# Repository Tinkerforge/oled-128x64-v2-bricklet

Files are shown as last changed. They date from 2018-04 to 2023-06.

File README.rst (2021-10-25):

OLED 128x64 Bricklet 2.0
========================

This repository contains the firmware source code and the hardware design
files. The documentation generator configs can be found at
https://github.com/Tinkerforge/generators

Repository Content
------------------

software/:
 * examples/: Examples for all supported languages
 * build/: Compiled files
 * src/: Source code of firmware
 * Makefile: Makefile to build project

hardware/:
 * Contains KiCad project files and additionally schematics as PDF

datasheets/:
 * Contains datasheets for sensors and complex ICs that are used

Hardware
--------

The hardware is designed with the open source EDA Suite KiCad
(http://www.kicad.org). Before you are able to open the files,
you have to install the Tinkerforge kicad-libraries
(https://github.com/Tinkerforge/kicad-libraries). You can either clone
them directly in hardware/ or clone them in a separate folder and
symlink them into hardware/
(ln -s kicad_path/kicad-libraries project_path/hardware). After that you
can open the .pro file in hardware/ with KiCad and from there view and
modify the schematics and the PCB layout.

Software
--------

If you want to do your own Brick/Bricklet firmware development we highly
recommend that you use our build environment setup script and read the
tutorial (https://www.tinkerforge.com/en/doc/Tutorials/Tutorial_Build_Environment/Tutorial.html).

To compile the C code we recommend you to install the newest GNU Arm Embedded
Toolchain (https://launchpad.net/gcc-arm-embedded/+download).
You also need to install bricklib2 (https://github.com/Tinkerforge/bricklib2).

You can either clone it directly in software/src/ or clone it in a
separate folder and symlink it into software/src/
(ln -s bricklib_path/bricklib2 project_path/software/src/). Finally make sure to
have CMake installed (http://www.cmake.org/cmake/resources/software.html).

After that you can build the firmware by invoking make in software/.
The firmware (.zbin) can then be found in software/build/ and uploaded
with brickv (click button "Flashing" on start screen).

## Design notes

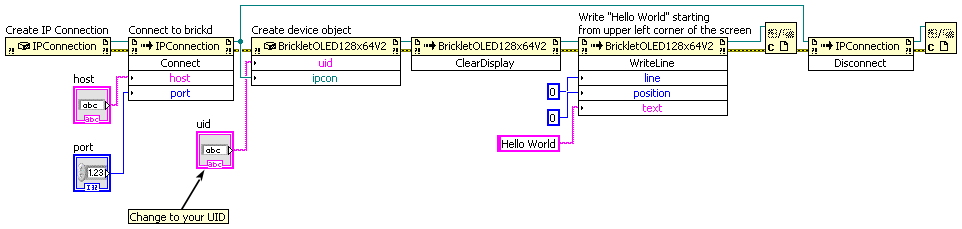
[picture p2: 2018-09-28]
software/examples/labview/Example Hello World.vi.png

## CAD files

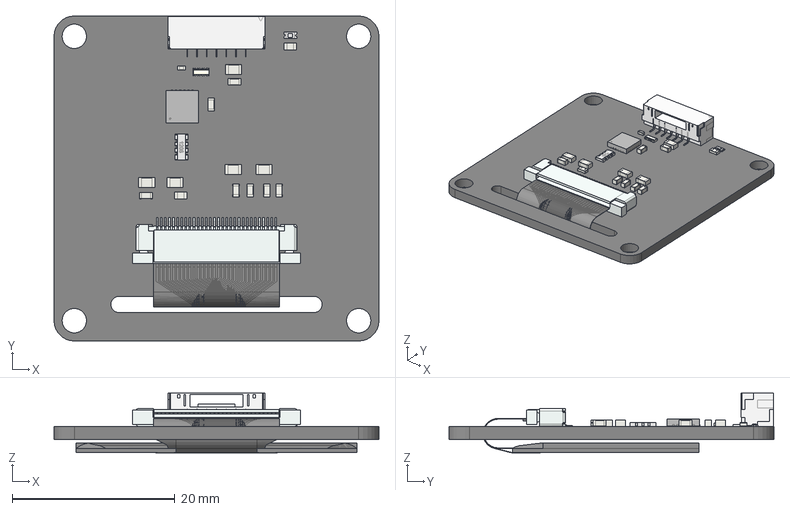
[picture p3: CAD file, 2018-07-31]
hardware/oled-128x64-v2.FCStd
40.0 x 40.0 x 7.38 mm
Pcb
C_0805_
C_0805_001
C_0805_002
C_0805_003
R_4x0603_
OLED_128x64_
CONN_OLED_128x64_
C_0805_004
C_0603_
C_0603_001
D_0603_blue_
BrickletConn_7pin_
R_0603_
QFN-24_4x4mm_Pitch0.5mm_
C_0402_
C_0603_002
C_0603_003
C_0603_004
C_0603_005
C_0603_006
R_0603_001

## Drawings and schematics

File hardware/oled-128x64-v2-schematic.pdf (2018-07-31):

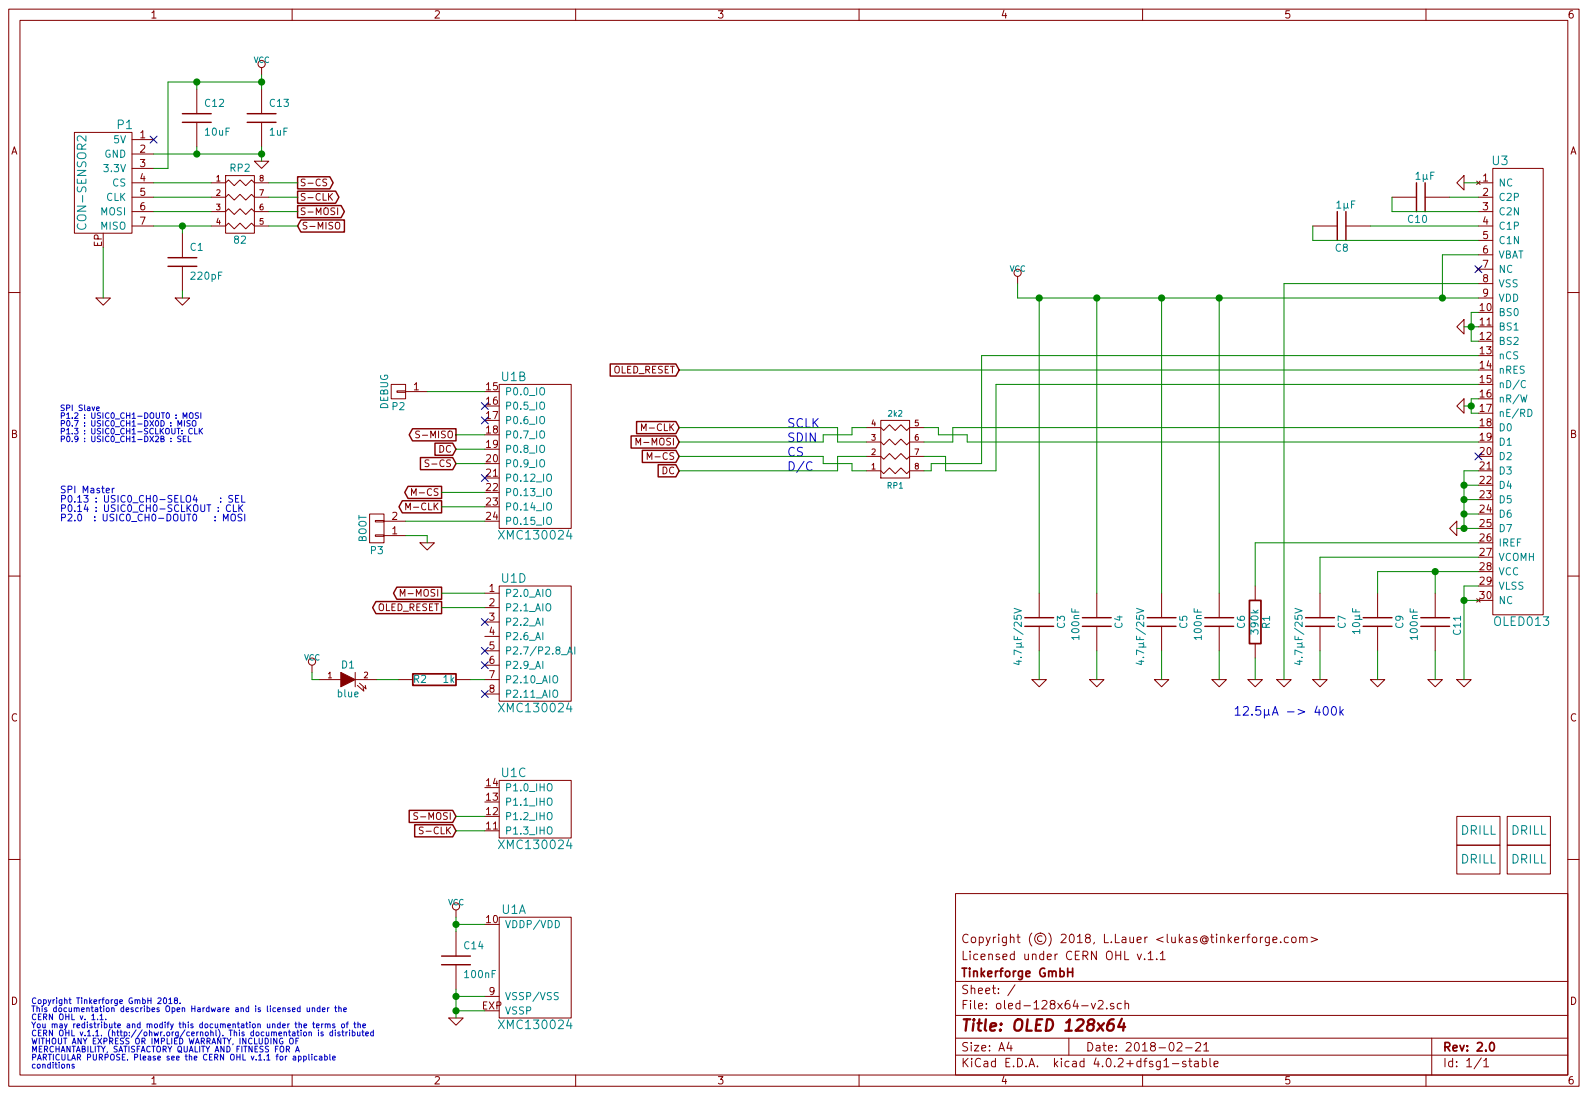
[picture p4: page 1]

VCC M-CS M-MOSI M-CLKDC C12

SPI Slave P1.2 : USIC0_CH1-DOUT0 : MOSI P0.7 : USIC0_CH1-DX0D : MISO

Licensed under CERN OHL v.1.1 Copyright (©) 2018, L.Lauer <lukas@tinkerforge.com>

File: oled-128x64-v2.sch Sheet: / Tinkerforge GmbH

Copyright Tinkerforge GmbH 2018. This documentation describes Open Hardware and is licensed under the CERN OHL v. 1.1. You may redistribute and modify this documentation under the terms of the CERN OHL v.1.1. (http://ohwr.org/cernohl). This documentation is distributed WITHOUT ANY EXPRESS OR IMPLIED WARRANTY, INCLUDING OF MERCHANTABILITY, SATISFACTORY QUALITY AND FITNESS FOR A

PARTICULAR PURPOSE. Please see the CERN OHL v.1.1 for applicable

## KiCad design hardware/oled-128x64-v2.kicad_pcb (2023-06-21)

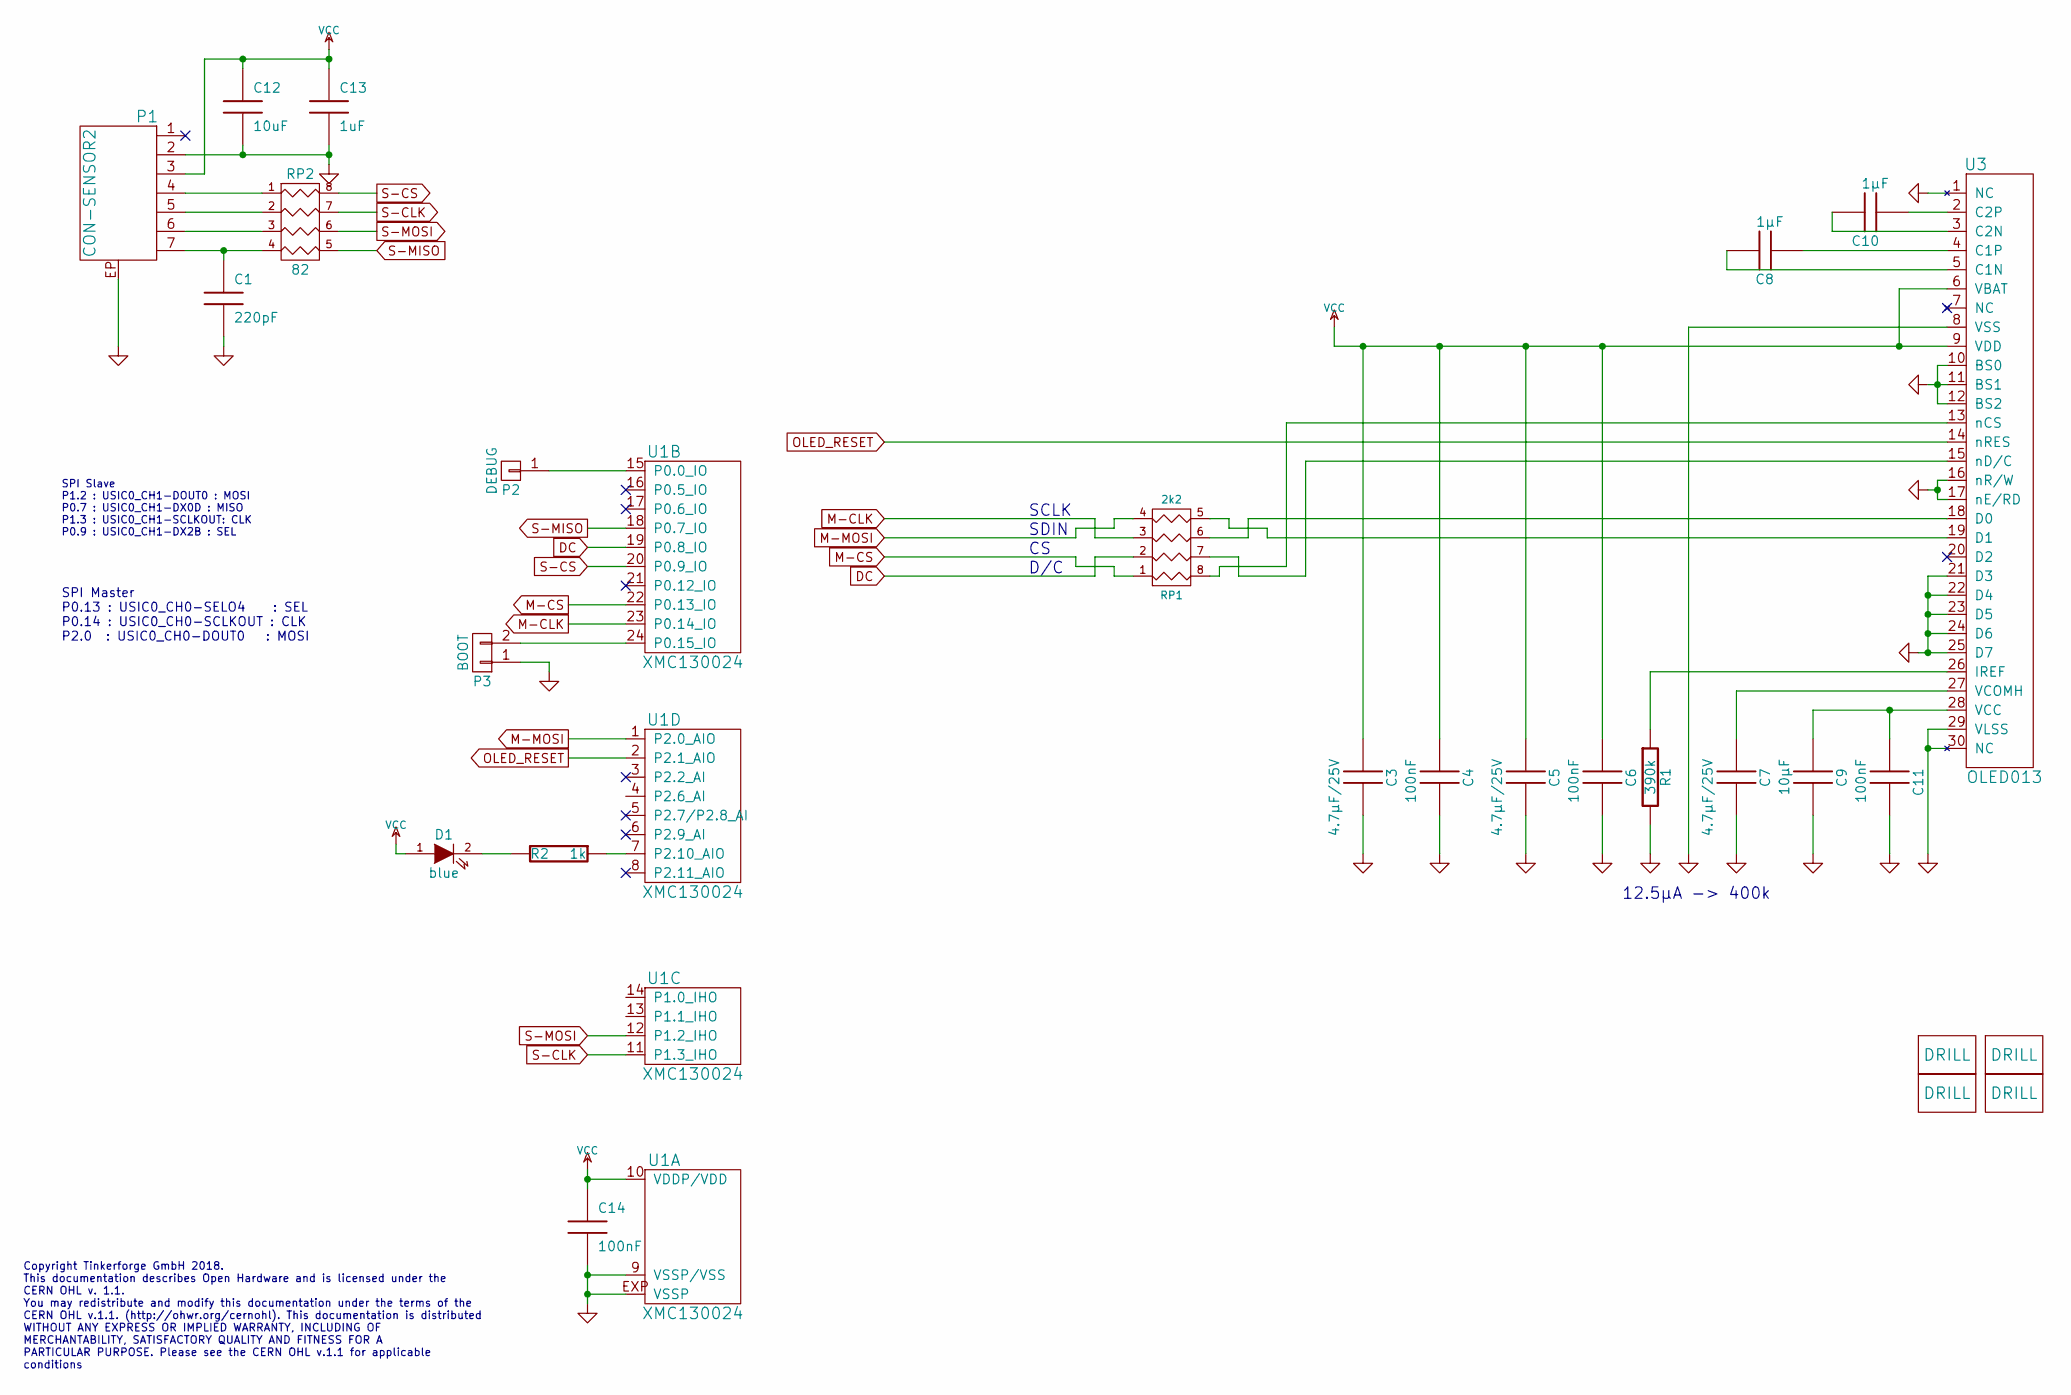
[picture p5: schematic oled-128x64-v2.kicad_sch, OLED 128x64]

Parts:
C1: 220pF; C0402F
C3, C5, C7: 4.7µF/25V; C0805
C4, C6, C11, C14: 100nF; C0603F
C8, C10: 1µF; C0603F
C9: 10µF; C0805
C12: 10uF; C0805
C13: 1uF; C0603F
D1: blue; D0603F
P1: CON-SENSOR2
P2: DEBUG; DEBUG_PAD
P3: BOOT; SolderJumper
R1: 390k; R0603F
R2: 1k; R0603F
RP1: 2k2; 0603X4
RP2: 82; 4X0402
U1: XMC130024; QFN24-4x4mm-0.5mm
U3: OLED013; ER-CON30HT-1
U4, U5, U6, U7: DRILL; DRILL_NP

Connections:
DC: RP1.2, U1.19 (P0.8_IO)
GND: C1.2, C3.1, C4.1, C5.1, C6.1, C7.1, C9.1, C11.1, C12.2, C13.2, C14.2, P1.2, P1.EP, P3.1, R1.2, U1.9 (VSSP/VSS), U1.EXP (VSSP), U3.1 (NC), U3.8 (VSS), U3.10 (BS0), U3.11 (BS1), U3.12 (BS2), U3.16 (nR/W), U3.17 (nE/RD), U3.21 (D3), U3.22 (D4), U3.23 (D5), U3.24 (D6), U3.25 (D7), U3.29 (VLSS), U3.30 (NC)
M-CLK: RP1.3, U1.23 (P0.14_IO)
M-CS: RP1.1, U1.22 (P0.13_IO)
M-MOSI: RP1.4, U1.1 (P2.0_AIO)
unnamed: C1.1, P1.7, RP2.4
unnamed: C7.2, U3.27 (VCOMH)
unnamed: C8.1, U3.5 (C1N)
unnamed: C8.2, U3.4 (C1P)
unnamed: C10.1, U3.3 (C2N)
unnamed: C10.2, U3.2 (C2P)
unnamed: C9.2, C11.2, U3.28 (VCC)
unnamed: D1.2 (K), R2.2
unnamed: P1.4, RP2.1
unnamed: P1.5, RP2.2
unnamed: P1.6, RP2.3
unnamed: P2.1, U1.15 (P0.0_IO)
unnamed: P3.2, U1.24 (P0.15_IO)
unnamed: R1.1, U3.26 (IREF)
unnamed: R2.1, U1.7 (P2.10_AIO)
unnamed: RP1.5 (R4), U3.19 (D1)
unnamed: RP1.6 (R3), U3.18 (D0)
unnamed: RP1.7 (R2), U3.15 (nD/C)
unnamed: RP1.8 (R1), U3.13 (nCS)
OLED_RESET: U1.2 (P2.1_AIO), U3.14 (nRES)
S-CLK: RP2.7 (R2), U1.11 (P1.3_IHO)
S-CS: RP2.8 (R1), U1.20 (P0.9_IO)
S-MISO: RP2.5 (R4), U1.18 (P0.7_IO)
S-MOSI: RP2.6 (R3), U1.12 (P1.2_IHO)
VCC: C3.2, C4.2, C5.2, C6.2, C12.1, C13.1, C14.1, D1.1 (A), P1.3, U1.10 (VDDP/VDD), U3.6 (VBAT), U3.9 (VDD)

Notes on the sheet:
SPI Slave P1.2 : USIC0_CH1-DOUT0 : MOSI P0.7 : USIC0_CH1-DX0D : MISO P1.3 : USIC0_CH1-SCLKOUT: CLK P0.9 : USIC0_CH1-DX2B : SEL
Copyright Tinkerforge GmbH 2018. This documentation describes Open Hardware and is licensed under the CERN OHL v. 1.1. You may redistribute and modify this documentation under the terms of the CERN OHL v.1.1. (http://ohwr.org/cernohl). This documentation is distributed WITHOUT ANY EXPRESS OR IMPLIE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
D/C
SDIN
12.5µA -> 400k
SCLK
SPI Master P0.13 : USIC0_CH0-SELO4 : SEL P0.14 : USIC0_CH0-SCLKOUT : CLK P2.0 : USIC0_CH0-DOUT0 : MOSI

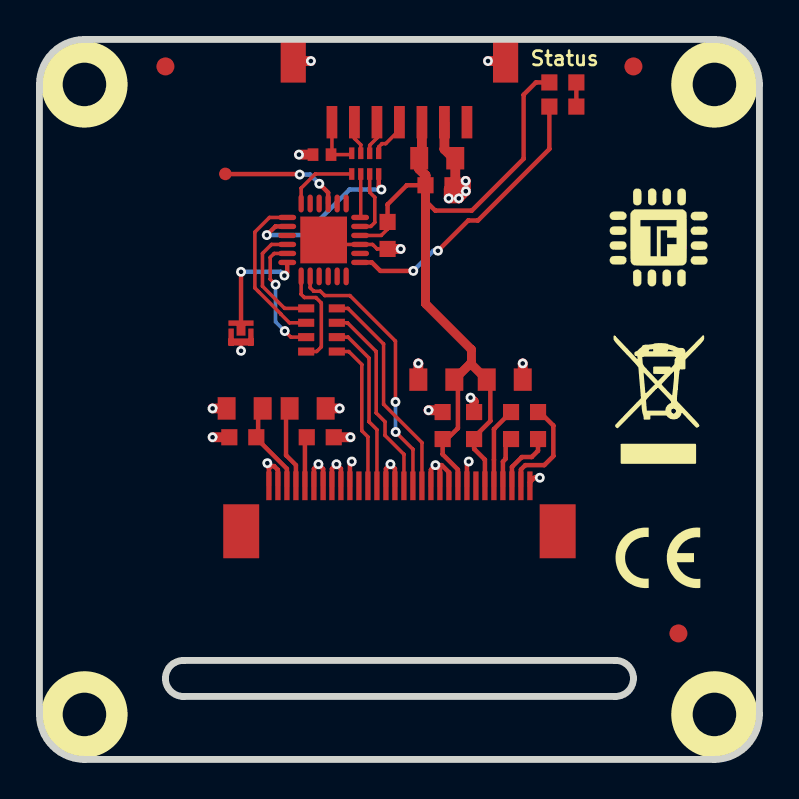
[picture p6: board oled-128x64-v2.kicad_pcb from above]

Board: 2 copper layers, 40.0 x 40.0 mm, 31 parts (0 on the bottom side), 30 nets.

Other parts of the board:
Fiducial_Mark: VAL**; Fiducial_Mark
Fiducial_Mark#2, Fiducial_Mark#3: VAL**; Fiducial_Mark
VAL: CE_5mm

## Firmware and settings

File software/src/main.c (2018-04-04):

/* oled-128x64-v2-bricklet
 * Copyright (C) 2018 Olaf Lüke <olaf@tinkerforge.com>
 *
 * main.c: Initialization for OLED 128x64 V2 Bricklet
 *
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
 * You should have received a copy of the GNU Lesser General Public
 * License along with this library; if not, write to the
 * Free Software Foundation, Inc., 59 Temple Place - Suite 330,
 * Boston, MA 02111-1307, USA.
 */

#include <stdio.h>
#include <stdbool.h>

#include "configs/config.h"

#include "bricklib2/bootloader/bootloader.h"
#include "bricklib2/hal/system_timer/system_timer.h"
#include "bricklib2/logging/logging.h"
#include "communication.h"
#include "ssd1306.h"

int main(void) {
	logging_init();
	logd("Start OLED 128x64 V2 Bricklet\n\r");

	communication_init();
	ssd1306_init();

	while(true) {
		bootloader_tick();
		communication_tick();
		ssd1306_tick();
	}
}

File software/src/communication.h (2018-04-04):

/* oled-128x64-v2-bricklet
 * Copyright (C) 2018 Olaf Lüke <olaf@tinkerforge.com>
 *
 * communication.h: TFP protocol message handling
 *
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
 * You should have received a copy of the GNU Lesser General Public
 * License along with this library; if not, write to the
 * Free Software Foundation, Inc., 59 Temple Place - Suite 330,
 * Boston, MA 02111-1307, USA.
 */

#ifndef COMMUNICATION_H
#define COMMUNICATION_H

#include <stdint.h>
#include <stdbool.h>

#include "bricklib2/protocols/tfp/tfp.h"
#include "bricklib2/bootloader/bootloader.h"

// Default functions
BootloaderHandleMessageResponse handle_message(const void *data, void *response);
void communication_tick(void);
void communication_init(void);

// Constants
#define OLED_128X64_V2_BOOTLOADER_MODE_BOOTLOADER 0
#define OLED_128X64_V2_BOOTLOADER_MODE_FIRMWARE 1
#define OLED_128X64_V2_BOOTLOADER_MODE_BOOTLOADER_WAIT_FOR_REBOOT 2
#define OLED_128X64_V2_BOOTLOADER_MODE_FIRMWARE_WAIT_FOR_REBOOT 3
#define OLED_128X64_V2_BOOTLOADER_MODE_FIRMWARE_WAIT_FOR_ERASE_AND_REBOOT 4

#define OLED_128X64_V2_BOOTLOADER_STATUS_OK 0
#define OLED_128X64_V2_BOOTLOADER_STATUS_INVALID_MODE 1
#define OLED_128X64_V2_BOOTLOADER_STATUS_NO_CHANGE 2
#define OLED_128X64_V2_BOOTLOADER_STATUS_ENTRY_FUNCTION_NOT_PRESENT 3
#define OLED_128X64_V2_BOOTLOADER_STATUS_DEVICE_IDENTIFIER_INCORRECT 4
#define OLED_128X64_V2_BOOTLOADER_STATUS_CRC_MISMATCH 5

#define OLED_128X64_V2_STATUS_LED_CONFIG_OFF 0
#define OLED_128X64_V2_STATUS_LED_CONFIG_ON 1
#define OLED_128X64_V2_STATUS_LED_CONFIG_SHOW_HEARTBEAT 2
#define OLED_128X64_V2_STATUS_LED_CONFIG_SHOW_STATUS 3

// Function and callback IDs and structs
#define FID_WRITE_PIXELS_LOW_LEVEL 1
#define FID_READ_PIXELS_LOW_LEVEL 2
#define FID_CLEAR_DISPLAY 3
#define FID_SET_DISPLAY_CONFIGURATION 4
#define FID_GET_DISPLAY_CONFIGURATION 5
#define FID_WRITE_LINE 6
#define FID_DRAW_BUFFERED_FRAME 7


typedef struct {
	TFPMessageHeader header;
	uint8_t x_start;
	uint8_t y_start;
	uint8_t x_end;
	uint8_t y_end;
	uint16_t pixels_length;
	uint16_t pixels_chunk_offset;
	uint8_t pixels_chunk_data[448/8];
} __attribute__((__packed__)) WritePixelsLowLevel;

typedef struct {
	TFPMessageHeader header;
	uint8_t x_start;
	uint8_t y_start;
	uint8_t x_end;
	uint8_t y_end;
} __attribute__((__packed__)) ReadPixelsLowLevel;

typedef struct {
	TFPMessageHeader header;
	uint16_t pixels_length;
	uint16_t pixels_chunk_offset;
	uint8_t pixels_chunk_data[480/8];
} __attribute__((__packed__)) ReadPixelsLowLevel_Response;

typedef struct {
	TFPMessageHeader header;
} __attribute__((__packed__)) ClearDisplay;

typedef struct {
	TFPMessageHeader header;
	uint8_t contrast;
	bool invert;
	bool automatic_draw;
} __attribute__((__packed__)) SetDisplayConfiguration;

typedef struct {
	TFPMessageHeader header;
} __attribute__((__packed__)) GetDisplayConfiguration;

typedef struct {
	TFPMessageHeader header;
	uint8_t contrast;
	bool invert;
	bool automatic_draw;
} __attribute__((__packed__)) GetDisplayConfiguration_Response;

typedef struct {
	TFPMessageHeader header;
	uint8_t line;
	uint8_t position;
	char text[22];
} __attribute__((__packed__)) WriteLine;

typedef struct {
	TFPMessageHeader header;
	bool force_complete_redraw;
} __attribute__((__packed__)) DrawBufferedFrame;


// Function prototypes
BootloaderHandleMessageResponse write_pixels_low_level(const WritePixelsLowLevel *data);
BootloaderHandleMessageResponse read_pixels_low_level(const ReadPixelsLowLevel *data, ReadPixelsLowLevel_Response *response);
BootloaderHandleMessageResponse clear_display(const ClearDisplay *data);
BootloaderHandleMessageResponse set_display_configuration(const SetDisplayConfiguration *data);
BootloaderHandleMessageResponse get_display_configuration(const GetDisplayConfiguration *data, GetDisplayConfiguration_Response *response);
BootloaderHandleMessageResponse write_line(const WriteLine *data);
BootloaderHandleMessageResponse draw_buffered_frame(const DrawBufferedFrame *data);

// Callbacks


#define COMMUNICATION_CALLBACK_TICK_WAIT_MS 1
#define COMMUNICATION_CALLBACK_HANDLER_NUM 0
#define COMMUNICATION_CALLBACK_LIST_INIT \


#endif

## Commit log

2018-02-16 Add schematic
    [oled-128x64.sch]
2018-02-20 Cleanup KiCad libraries config
    Ensure LibDir=kicad-libraries and LibName1=tinkerforge.
    Remove special library.
2018-02-21 Change a few pins because of the layout
    [oled-128x64.sch]
2018-02-21 Add layout
    [oled-128x64.kicad_pcb]
2018-02-21 Fix ground plane
    [oled-128x64.kicad_pcb]
2018-03-13 Fix orientation of our logos
    [oled-128x64.kicad_pcb]
2018-03-28 Add initial stub version of firmware
    [cmake_config_custom.txt]
2018-04-03 Add correct pin definitions
    [config_custom_bootloader.h, config_custom_bootstrapper.h]
2018-04-04 Implement SSD1306 driver and API
2018-05-11 Rename files
    [oled-128x64-v2.kicad_pcb, oled-128x64-v2.sch]
2018-06-06 set origin
    [oled-128x64-v2.kicad_pcb]
2018-06-07 add text
    [oled-128x64-v2.kicad_pcb]
2018-06-18 Change footprint to x0402F/x0603F
    [oled-128x64-v2.kicad_pcb, oled-128x64-v2.sch]
2018-07-31 Add 3d model (*.FCStd & *.step)
    [oled-128x64-v2.FCStd, oled-128x64-v2.kicad_pcb]
2018-07-31 Add PDF schematic
2019-05-28 Improve SPI IRQ performance
    Use local pointer to save the time for accessing the struct
2020-09-02 uc: Add example driver note.
2021-10-25 Update KiCad link
    https://www.kicad.org/blog/2021/10/Avoid-links-to-former-kicad-domain/
2023-06-21 move to new kicad version
    [oled-128x64-v2.kicad_pcb, oled-128x64-v2.kicad_sch, oled-128x64-v2.sch]
